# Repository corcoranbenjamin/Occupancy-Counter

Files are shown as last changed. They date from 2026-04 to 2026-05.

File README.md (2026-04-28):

# Occupancy Counter — VL53L5CX + ESP32-C6

Real-time room occupancy tracking using a time-of-flight sensor, with cloud logging to Google Sheets and a live Grafana dashboard.

<p align="center">
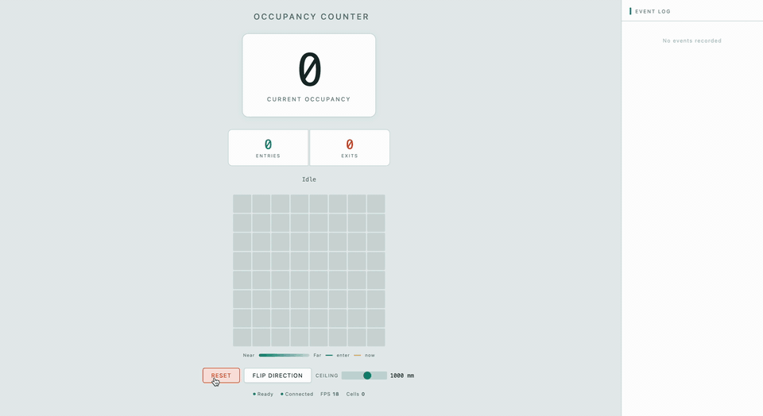
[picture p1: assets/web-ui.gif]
Live web UI showing the 8x8 sensor grid, occupancy count, entries, exits, and event log
  
</p>

A VL53L5CX 8×8 multizone ToF sensor points straight down from above a doorway. At 15 Hz it produces a grid of distance readings. When someone walks through, their head and shoulders appear as a cluster of cells closer than the learned baseline. The firmware detects those clusters, tracks them across the sensor's field of view, and based on the direction of travel classifies each crossing as an **entry** or **exit**.

The ESP32-C6 connects to WiFi (WPA2-Enterprise/eduroam by default, with a WPA2-PSK option for testing), logs snapshots to a Google Sheet, and optionally writes daily CSV files to a micro SD card. Uploads only happen when the doorway is clear so the tracking pipeline is never interrupted by network I/O. A Grafana Cloud dashboard reads the Sheet and displays live occupancy, entries, exits, and occupancy-over-time. The device deep-sleeps outside configurable hours and restores its calibration baseline from flash on wake.

---

## Hardware

| Component | Role |
|---|---|
| **VL53L5CX** (Pololu carrier board) | 8×8 multizone time-of-flight sensor, up to 4 m range |
| **ESP32-C6** | WiFi-capable RISC-V microcontroller running the firmware |
| **Micro SD breakout module** | Optional local CSV logging (SPI) |
| **Momentary push button** on GPIO3 | Hold 2 s to reset counts and clear saved baseline |

### Wiring

**Sensor (I2C):** `VIN→3V3` · `GND→GND` · `SDA→GPIO6` · `SCL→GPIO7` · `LPn→3V3` · `INT→GPIO5`

**SD card (SPI):** `CS→GPIO1` · `SCK→GPIO18` · `MOSI→GPIO19` · `MISO→GPIO20`

**Reset button:** `GPIO3→GND` (uses internal pull-up)

---

## Getting Started

### Prerequisites

- **Arduino IDE** or **arduino-cli** with the **ESP32** board package (≥ 3.x)
- Board selection: **ESP32C6 Dev Module**
- **USB CDC On Boot** must be **Enabled** in board settings for serial output

### Libraries

| Library | Purpose |
|---|---|
| [SparkFun VL53L5CX](https://github.com/sparkfun/SparkFun_VL53L5CX_Arduino_Library) | Sensor driver |
| [ESP-Google-Sheet-Client](https://github.com/mobizt/ESP-Google-Sheet-Client) | Google Sheets API with service-account auth |
| [ESP32WiFiEnterprise](https://github.com/racoonx65/WiFiEnterprise) | WPA2-Enterprise (eduroam) support |

### Setup

1. Clone this repo
2. Copy `secrets_template.h` → `secrets.h`
3. Fill in your eduroam credentials, GCP service account, and Spreadsheet ID
4. (Optional) To use a home WiFi network instead of eduroam, uncomment `USE_HOME_WIFI` and set `HOME_SSID` / `HOME_PASSWORD` in `secrets.h`
5. Flash to ESP32-C6
6. Keep the doorway clear for ~2 seconds while the sensor calibrates

### Google Sheets

Create a Google Sheet with a tab named **Data**. Share it with your GCP service account email (Editor). The firmware appends rows starting at `Data!A2`:

| Column A | Column B | Column C | Column D | Column E |
|---|---|---|---|---|
| EpochTimestamp | Occupancy Count | Entry | Exit | Time (EST) |

### Grafana Dashboard

1. Install the **Google Sheets** data source plugin in Grafana Cloud
2. Configure with your API key and Spreadsheet ID
3. Import `grafana-dashboard.json`
4. The chart panel needs two transformations: convert `EpochTimestamp` to Time (format `X`), convert `Occupancy Count` to Number

| Panel | Type | Color |
|---|---|---|
| Occupancy | Stat (big number) | `#3A82FF` blue |
| Entries | Stat | `#34D399` mint |
| Exits | Stat | `#F87171` coral |
| Occupancy Over Time | Time series | `#22D3EE` cyan |

<p align="center">
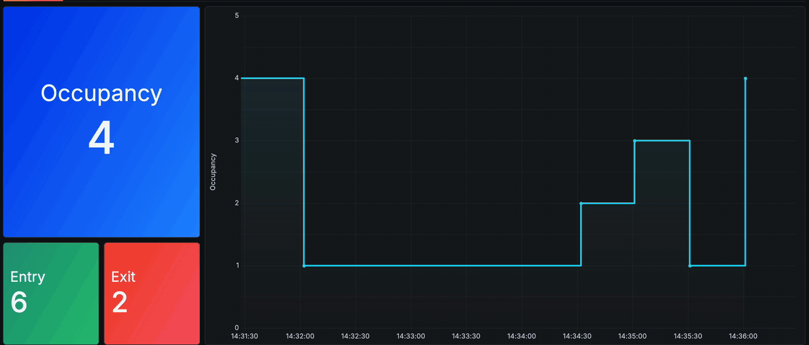
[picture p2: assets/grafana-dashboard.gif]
Grafana dashboard showing live occupancy, entries, exits, and occupancy-over-time chart
  
</p>

---

## How It Works

### Detection & Tracking Pipeline

Each frame at ~15 Hz runs through this pipeline:

1. **Validate** — accept cells with `target_status` 5, 6, or 9 (per VL53L5CX datasheet UM2884) and distance > 0
2. **Min-distance filter** — rolling minimum over the last 3 frames per cell, reducing multipath noise (UM2600 §6.2)
3. **Occupied mask** — a cell is occupied if its filtered distance is above `DETECT_FLOOR_MM` (100 mm), below `DETECT_CEILING_MM` (1000 mm), and after calibration at least `STATIC_MARGIN_MM` (100 mm) shorter than its baseline
4. **BFS blob detection** — flood-fill finds connected clusters of occupied cells; blobs smaller than `MIN_BLOB_SIZE` (2 cells) are discarded
5. **Greedy association** — each blob is matched to its nearest existing track by centroid distance (within 3.0 grid cells)
6. **Track expiry** — unmatched tracks accumulate misses; after a grace period (5 frames) or total timeout (90 frames), the track is evaluated
7. **Spawn** — unmatched blobs become new tracks
8. **Direction evaluation** — `shift = last_row − enter_row`; if the shift exceeds 1.5 rows and the track lived for ≥3 frames, the direction relative to `ENTRY_DIR` determines entry vs exit; occupancy is incremented or decremented accordingly

### Idle-Only Uploads

Google Sheets uploads and SD card writes only occur when `tracking_active` is false (no one in the doorway). This prevents blocking HTTPS calls from stalling the tracking pipeline and causing missed frames or false counts. Data is buffered and sent the moment the doorway clears.

### Calibration & Baseline Persistence

On first boot the sensor averages 30 frames (~2 s) of the empty doorway to learn a per-cell baseline. This baseline is saved to ESP32 NVS flash. On subsequent boots (including wake from deep sleep) the baseline is restored automatically — no recalibration delay.

Holding the reset button for 2 seconds clears the saved baseline, resets all counters, and starts a 10-second countdown so you can clear the doorway before calibration begins.

### Sleep Schedule

When `SLEEP_ENABLED` is set (default), the device:
- Checks the clock every 30 seconds
- At 21:30 (configurable): resets counts, uploads a final row, saves baseline to flash, stops the sensor, unmounts the SD card, turns off WiFi, and enters deep sleep
- At 06:30 (configurable): wakes via timer, reboots, reconnects, restores baseline, and starts tracking with fresh counters
- If it boots outside the active window, it immediately sleeps until the next wake time
- Each sleep is capped at 1 hour for timer reliability; `setup()` re-evaluates on each wake

### SD Card Logging

When `SD_ENABLED` is set (default), a CSV row is written to `/YYYY-MM-DD.csv` on the SD card every 5 minutes (configurable via `SD_LOG_INTERVAL_MS`), independent of the Sheets upload interval. Like Sheets uploads, SD writes only occur when the doorway is clear.

---

## Project Structure

```
OccupancyCounter/
├── OccupancyCounter.ino       Main sketch (setup, loop, WiFi, Sheets, SD, sleep)
├── config.h                    All tuneable constants
├── tracking.h                  OccupancyTracker class (algorithm + NVS persistence)
├── secrets_template.h          Credential placeholders — copy to secrets.h
├── grafana-dashboard.json      Importable Grafana dashboard
├── assets/                     Demo GIFs used in this README
├── tools/
│   └── debug-display/          Standalone debugging sketch (see below)
├── .gitignore                  Excludes secrets.h
└── README.md                   This file
```

---

## Debugging Tools

A standalone debugging sketch lives at [`tools/debug-display/`](tools/debug-display/) for sponsors and future teams who want to validate sensor placement, watch the tracking algorithm in real time, or tune detection thresholds without setting up the full cloud stack.

It runs on the same hardware as the production firmware but replaces Google Sheets and Grafana with a self-hosted WiFi access point and an in-browser visualization of the 8x8 distance grid, occupied cells, blobs, tracks, and entry/exit decisions. No `secrets.h` is required.

See [`tools/debug-display/README.md`](tools/debug-display/README.md) for full instructions, and [`tools/debug-display/CODE_WALKTHROUGH.md`](tools/debug-display/CODE_WALKTHROUGH.md) for a line-by-line explanation of the tracking algorithm aimed at someone reading it for the first time.

---

## Configuration Reference

All compile-time constants are in `config.h`.

### Pins

| Constant | Value | Purpose |
|---|---|---|
| `SDA_PIN` | 6 | I2C data |
| `SCL_PIN` | 7 | I2C clock |
| `INT_PIN` | 5 | Sensor interrupt (active LOW) |
| `RESET_BUTTON_PIN` | 3 | Reset button (active LOW, internal pull-up) |
| `SD_CS_PIN` | 1 | SD chip select |
| `SD_CLK_PIN` | 18 | SD clock |
| `SD_MOSI_PIN` | 19 | SD MOSI |
| `SD_MISO_PIN` | 20 | SD MISO |

### Sensor & Detection

| Constant | Value | Purpose |
|---|---|---|
| `SENSOR_FREQ_HZ` | 15 | Ranging frequency (Hz) |
| `DETECT_FLOOR_MM` | 100 | Ignore closer than this (near-field noise) |
| `DETECT_CEILING_MM` | 1000 | Detection ceiling (mm below sensor) |
| `STATIC_MARGIN_MM` | 100 | Min baseline–reading delta to count as occupied |

### Tracking

| Constant | Value | Purpose |
|---|---|---|
| `MAX_BLOBS` / `MAX_TRACKS` | 4 | Simultaneous blob/track limit |
| `MIN_BLOB_SIZE` | 2 | Min cells for a valid blob |
| `MAX_ASSOC_DIST` | 3.0 | Max centroid distance for track↔blob match |
| `MIN_CROSSING_FRAMES` | 3 | Min frames for a real crossing (~200 ms) |
| `MAX_CROSSING_FRAMES` | 90 | Timeout for lingering track (~6 s) |
| `MIN_CENTROID_SHIFT` | 1.5 | Min row shift to count as a crossing |
| `MISS_GRACE_FRAMES` | 5 | Frames to tolerate dropout (~333 ms) |
| `ENTRY_DIR` | -1 | Row direction that counts as entry |
| `MIN_FILTER_DEPTH` | 3 | Rolling min-filter window (frames) |

### Calibration

| Constant | Value | Purpose |
|---|---|---|
| `CALIB_FRAMES` | 30 | Frames to average for baseline (~2 s) |
| `CALIB_MAX_DIST_MM` | 4000 | Default baseline for cells with no valid readings |

### Sleep Schedule

| Constant | Value | Purpose |
|---|---|---|
| `SLEEP_ENABLED` | 1 | Set to 0 to run 24/7 |
| `SLEEP_HOUR` / `SLEEP_MINUTE` | 21 / 30 | Sleep at 9:30 PM |
| `WAKE_HOUR` / `WAKE_MINUTE` | 6 / 30 | Wake at 6:30 AM |
| `SLEEP_CHECK_INTERVAL_MS` | 30000 | Clock check interval |

### Networking & Logging

| Constant | Value | Purpose |
|---|---|---|
| `SHEETS_UPLOAD_INTERVAL_MS` | 30000 | Sheets upload every 30 s (when idle) |
| `SD_LOG_INTERVAL_MS` | 300000 | SD backup every 5 min (when idle) |
| `WIFI_CHECK_INTERVAL_MS` | 5000 | WiFi health check interval |
| `MAX_RECONNECT_ATTEMPTS` | 5 | Reconnect cap per boot |
| `NTP_SERVER` | `pool.ntp.org` | Time server |
| `TZ_INFO` | `EST5EDT,...` | POSIX timezone (Eastern + DST) |
| `SD_ENABLED` | 1 | Set to 0 to disable SD logging |

---

## Serial Monitor Reference

| Tag | Meaning | Example |
|---|---|---|
| `[INIT]` | Sensor init | `[INIT] 8x8 @ 15 Hz, INT on GPIO5` |
| `[WIFI]` | WiFi status | `[WIFI] Connected — IP 10.0.0.50  RSSI -45 dBm` |
| `[TIME]` | NTP sync | `[TIME] NTP configured` |
| `[AUTH]` | Sheets token | `[AUTH] OAuth2.0 access token — ready` |
| `[CAL]` | Calibration | `[CAL] Baseline restored from flash — skipping calibration` |
| `[RUN]` | Tracking active | `[RUN] Active — ceiling 1000 mm, shift 1.5 rows, max 4 tracks` |
| `[SHEET]` | Upload result | `[SHEET] OK — occ:1  in:3  out:2  heap:177536` |
| `[SD]` | SD card | `[SD] Card mounted — 7640MB` |
| `[SLEEP]` | Sleep events | `[SLEEP] 21:30 — time to sleep` |
| `[BTN]` | Button reset | `[BTN] Reset — clear the doorway!` |

---

## Daily Lifecycle

1. **06:30** — ESP32 wakes from deep sleep, reboots
2. WiFi connects, NTP syncs, Google Sheets authenticates, SD card mounts
3. Baseline restored from flash — tracking starts immediately
4. Counts begin at zero for the new day
5. Occupancy logged to Sheet every 30 s and SD every 5 min (only when doorway is clear); Grafana auto-refreshes
6. **21:30** — counts reset, final upload, baseline saved, sensor stopped, SD unmounted, WiFi off, deep sleep
7. Repeat

---

## References

- [VL53L5CX Datasheet (UM2884)](https://www.st.com/resource/en/user_manual/um2884-a-guide-to-using-the-vl53l5cx-multizone-timeofflight-ranging-sensor-with-wide-field-of-view-ultra-lite-driver-uld-s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) — target_status codes, resolution modes
- [VL53L5CX datasheet (DS13754)](https://www.st.com/resource/en/datasheet/vl53l5cx.pdf) — module specs, FoV, range performance, power; ranging mode overview (full ULD API and output fields in UM2884 above)
- [People-Counting App Note (UM2600)](https://www.st.com/resource/en/user_manual/um2600-counting-people-with-the-vl53l1x-longdistance-ranging-timeofflight-sensor-stmicroelectronics.pdf) — min-distance filter (§6.2); originally for VL53L1X, technique adapted here
- [SparkFun VL53L5CX Library](https://github.com/sparkfun/SparkFun_VL53L5CX_Arduino_Library)
- [ESP-Google-Sheet-Client](https://github.com/mobizt/ESP-Google-Sheet-Client)
- [ESP32WiFiEnterprise](https://github.com/racoonx65/WiFiEnterprise)

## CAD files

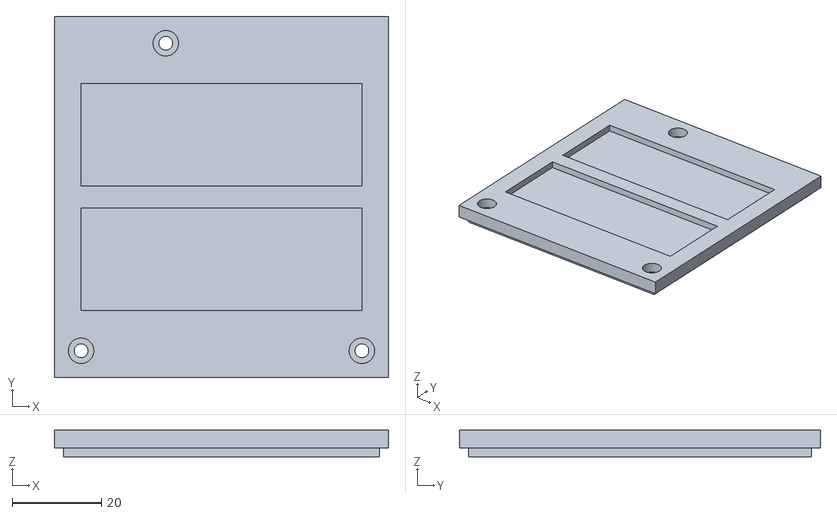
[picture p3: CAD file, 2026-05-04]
Enclosure CAD Files/Final_Enclosure_Lid.stl
75.0 x 81.0 x 6.00

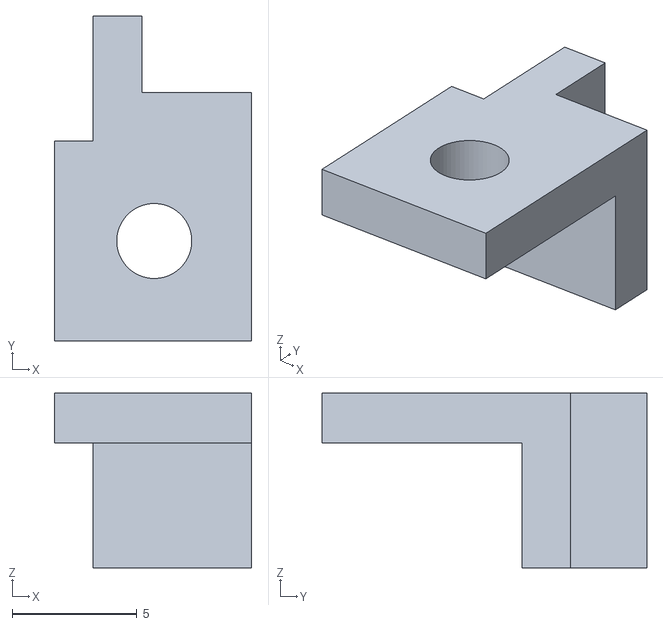
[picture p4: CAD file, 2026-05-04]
Enclosure CAD Files/Button_Holder.stl
7.90 x 13.0 x 7.00

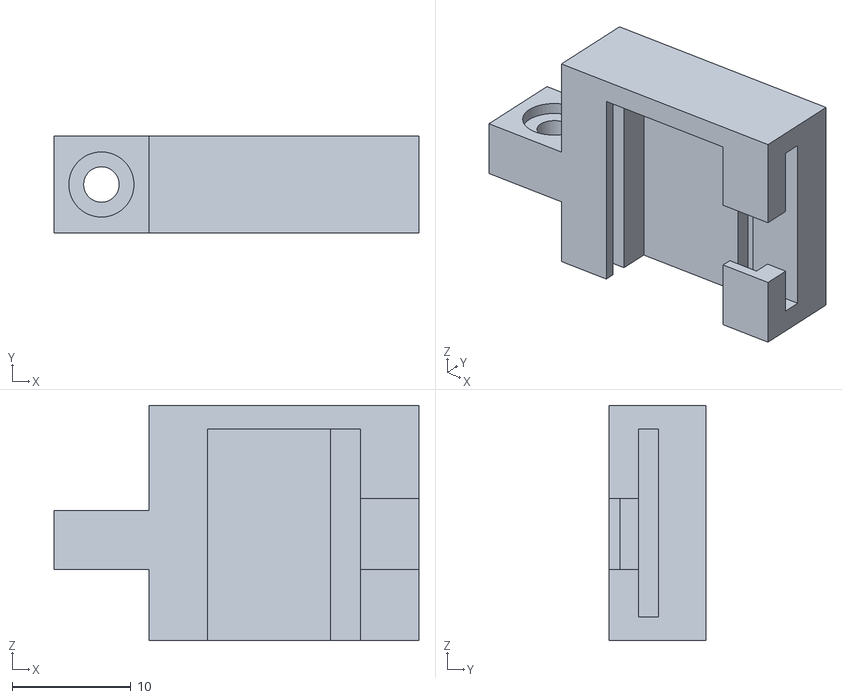
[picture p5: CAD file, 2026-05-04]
Enclosure CAD Files/ToF_Holder.stl
30.8 x 8.20 x 19.9

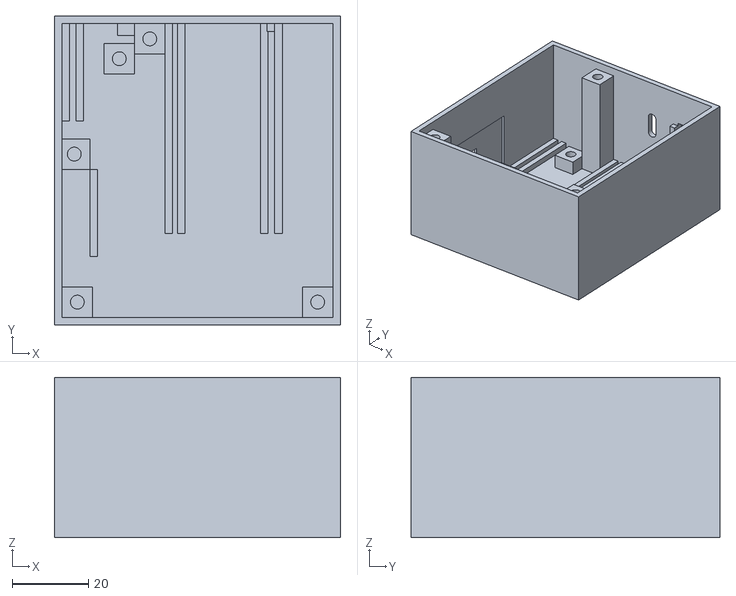
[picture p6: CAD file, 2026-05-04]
Enclosure CAD Files/Final_Enclosure.stl
75.0 x 81.0 x 42.0

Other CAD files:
Enclosure CAD Files/Button_Holder.f3d
Enclosure CAD Files/Final_Enclosure.f3d
Enclosure CAD Files/Final_Enclosure_Lid.f3d
Enclosure CAD Files/ToF_Holder.f3d

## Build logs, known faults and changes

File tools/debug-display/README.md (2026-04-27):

# Tracking Debug Display

A standalone Arduino sketch for visually debugging the VL53L5CX tracking algorithm. It runs on the same hardware as the production firmware but replaces the cloud logging stack with a self-hosted WiFi access point and an in-browser debug page.

Use it for sensor placement, calibration validation, and tuning the tracker without needing eduroam, Google Sheets, or Grafana.

---

## What it shows

When you join the device's access point and load `http://192.168.4.1` you get a live page with:

- The full 8x8 distance grid, color-coded by depth.
- The learned baseline distance for each cell.
- The occupied mask after baseline subtraction.
- Detected blobs (BFS connected components) with their centroids.
- Persistent tracks across frames, including their `enter_row -> last_row` shift.
- Live entry / exit counts and the most recent crossing decision.

This makes it easy to answer questions like:

- Is the sensor mounted high enough?
- Is the baseline being learned with the doorway actually clear?
- Is a person being detected as one blob or fragmenting into several?
- Is the row-shift threshold appropriate for this doorway width?

The web UI is the same one shown in the GIF at the top of the parent repository's README.

---

## Hardware

Identical to the production firmware (parent repo `OccupancyCounter.ino`):

| Pin | Connection |
|---|---|
| `GPIO6` | I2C SDA |
| `GPIO7` | I2C SCL |
| `GPIO5` | Sensor INT |
| `GPIO3` | Reset button to GND |
| `3V3` / `GND` | Sensor power, sensor `LPn` tied to `3V3` |

Board: **ESP32C6 Dev Module** (`esp32` core 3.x).

The SD card and Google Sheets pipeline are not used here — the debug build only needs the sensor and the ESP32.

---

## Library

- [SparkFun VL53L5CX Arduino Library](https://github.com/sparkfun/SparkFun_VL53L5CX_Arduino_Library)

That is the only required library. No `secrets.h`, no service account, no eduroam credentials.

---

## Usage

1. Open `TrackingDebugDisplay.ino` in the Arduino IDE.
2. Select board: **ESP32C6 Dev Module**, with **USB CDC On Boot** enabled.
3. Hold `BOOT` while plugging in the USB cable, then upload.
4. Once flashed, the device broadcasts an open SSID:
   - **SSID:** `OccupancyCounter`
   - **Password:** `12345678`
5. Connect a laptop or phone to that SSID.
6. Browse to **http://192.168.4.1**.
7. Hold the reset button for 2 s to wipe the saved baseline and recalibrate (clear the doorway during the 10 s countdown).

---

## How it relates to the production firmware

| | Production (`OccupancyCounter.ino`) | Debug display (this folder) |
|---|---|---|
| WiFi | WPA2-Enterprise (eduroam) or WPA2-PSK | Open access point hosted by the device |
| Logging | Google Sheets + SD card CSV | None — live web UI only |
| Dashboard | Grafana Cloud | Built-in HTML page |
| Sleep schedule | 21:30 - 06:30 deep sleep | Always on while powered |
| Tracking algorithm | Identical | Identical |

Both sketches share the same `tracking.h` algorithm philosophy (multi-blob BFS, greedy track association, row-shift direction evaluation) but each carries its own copy. **Do not try to share `tracking.h` between the two folders** — they are tuned independently and may diverge over time.

---

## Further reading

- [`CODE_WALKTHROUGH.md`](CODE_WALKTHROUGH.md) — line-by-line explanation of the tracking algorithm written for someone learning it for the first time.
- Parent repo [README](../../README.md) — full project context, production firmware, dashboard setup.

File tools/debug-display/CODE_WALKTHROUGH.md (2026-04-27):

# Occupancy Counter VL53L5CX — Code Walkthrough

## What This Project Does

A VL53L5CX time-of-flight sensor is mounted on the ceiling above a doorway, pointing straight down. It outputs an 8×8 grid of distance measurements 15 times per second. When a person walks underneath, some cells read closer than the empty doorway. The software detects those clusters, tracks them as they move across rows, and when they disappear off the other side, decides: was that an entry or an exit?

An ESP32-C3 microcontroller runs the sensor, the tracking algorithm, and a WiFi access point with a web dashboard showing the live count.

### Hardware

| Component | Role |
|---|---|
| **VL53L5CX** (on Pololu carrier board) | 8×8 multizone time-of-flight sensor, up to 4 m range |
| **ESP32-C3-DevKitC-02** | WiFi-capable RISC-V microcontroller running the firmware |
| **Physical button** on GPIO9 | Hold 2 seconds to reset counts |

Wiring: `VIN→3V3`, `GND→GND`, `SDA→GPIO4`, `SCL→GPIO5`, `LPn→3V3`, `INT→GPIO6`.

### References

- **VL53L5CX datasheet (UM2884):** [st.com/resource/en/user_manual/um2884](https://www.st.com/resource/en/user_manual/um2884-a-guide-to-using-the-vl53l5cx-multizone-timeofflight-ranging-sensor-with-a-wide-field-of-view-stmicroelectronics.pd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) — target_status codes, resolution modes, ranging frequency
- **VL53L5CX ranging guide (UM2600):** [st.com/resource/en/user_manual/um2600](https://www.st.com/resource/en/user_manual/um2600-vl53l1x-ranging-and-calibration-guide-stmicroelectronics.pdf) — min-distance filter technique (§6.2)
- **SparkFun VL53L5CX Arduino Library:** [github.com/sparkfun/SparkFun_VL53L5CX_Arduino_Library](https://github.com/sparkfun/SparkFun_VL53L5CX_Arduino_Library) — the driver used to communicate with the sensor
- **ESP32-C3 Technical Reference:** [docs.espressif.com](https://docs.espressif.com/projects/esp-idf/en/latest/esp32c3/) — GPIO interrupts, I2C, WiFi AP mode
- **Arduino ESP32 Core:** [github.com/espressif/arduino-esp32](https://github.com/espressif/arduino-esp32) — `WebServer`, `WiFi`, `Wire` libraries

---

## Project Structure

```
OccupancyCounterVL53L5CX/
├── OccupancyCounterVL53L5CX.ino   Main Arduino sketch (setup, loop, web server)
├── config.h                        All tuneable constants (pins, thresholds, timing)
├── tracking.h                      OccupancyTracker class (the detection/tracking algorithm)
└── web_page.h                      HTML/CSS/JS dashboard served by the ESP32
```

---

## File-by-File Breakdown

---

### config.h — Tuneable Constants

This file contains only `#define` values. It is the single place to adjust behavior without touching logic. Every constant is used by name in the other files.

#### Pin Definitions

| Constant | Value | Purpose |
|---|---|---|
| `SDA_PIN` | 4 | I2C data line to the VL53L5CX |
| `SCL_PIN` | 5 | I2C clock line to the VL53L5CX |
| `INT_PIN` | 6 | Interrupt line — sensor pulls LOW when a new frame is ready |
| `RESET_BUTTON_PIN` | 9 | Physical button; hold 2 s to reset occupancy counts |

#### WiFi

| Constant | Value | Purpose |
|---|---|---|
| `AP_MODE` | (defined) | Enables Access Point mode — the ESP32 creates its own WiFi network |
| `AP_SSID` | `"OccupancyCounter"` | Network name |
| `AP_PASSWORD` | `"12345678"` | Network password |
| `STA_MODE` | (commented out) | Alternative: connect to an existing network as a client |

Only one mode should be active at a time. If `STA_MODE` is enabled and the connection fails, the code falls back to AP mode automatically.

#### Sensor

| Constant | Value | Purpose |
|---|---|---|
| `SENSOR_I2C_ADDR` | `0x29` | Default I2C address of the VL53L5CX (per UM2884 §3.2) |
| `SENSOR_FREQ_HZ` | 15 | Frames per second. The sensor supports 1–60 Hz; 15 balances responsiveness and power |
| `I2C_CLOCK_HZ` | 400000 | 400 kHz I2C Fast Mode |

#### Detection

| Constant | Value | Purpose |
|---|---|---|
| `DETECT_CEILING_MM` | 1000 | Anything closer than 1000 mm (1 m) below the sensor is "something is there." Adjustable at runtime via the web UI slider (200–2000 mm range). |

#### Tracking Parameters

| Constant | Value | Purpose |
|---|---|---|
| `MAX_BLOBS` | 4 | Maximum simultaneous blob detections per frame |
| `MAX_TRACKS` | 4 | Maximum simultaneous persistent tracks |
| `MIN_BLOB_SIZE` | 2 | Minimum connected occupied cells to count as a real blob (rejects single-cell noise) |
| `MAX_ASSOC_DIST` | 3.0 | Maximum centroid distance (in grid cells) for matching a blob to an existing track between frames |
| `MIN_CROSSING_FRAMES` | 3 | A track must last at least 3 frames (~200 ms) to count as a real crossing (rejects brief noise) |
| `MAX_CROSSING_FRAMES` | 90 | A track lasting more than 90 frames (~6 s) is force-expired (person standing still, not crossing) |
| `MIN_CENTROID_SHIFT` | 1.5 | The centroid must move at least 1.5 grid rows from entry to exit to count (rejects partial entries) |
| `MISS_GRACE_FRAMES` | 5 | If a track loses its blob match for 5 consecutive frames (~333 ms), expire it (handles brief sensor dropouts) |
| `ENTRY_DIR` | -1 | Which row direction is "entering." `1` = moving toward higher rows = entry. `-1` = moving toward lower rows = entry. Flippable at runtime via the web UI. |

#### Noise Filtering

| Constant | Value | Purpose |
|---|---|---|
| `MIN_FILTER_DEPTH` | 3 | Keep the last 3 frames per cell, take the minimum distance. This is the "min-distance filter" recommended in ST's ranging guide (UM2600 §6.2). Smooths out transient noise spikes. |
| `STATIC_MARGIN_MM` | 100 | After calibration, a cell must be at least 100 mm closer than baseline to be "occupied." This rejects the door frame, walls, and floor from being detected as people. |

#### Calibration

| Constant | Value | Purpose |
|---|---|---|
| `CALIB_FRAMES` | 30 | Average 30 frames (~2 seconds at 15 Hz) of the empty doorway to learn the baseline distances |
| `CALIB_MAX_DIST_MM` | 4000 | If a cell never got a valid reading during calibration, assume 4000 mm (sensor max range) |

---

### tracking.h — The OccupancyTracker Class

This is the brain of the system. It contains all detection, tracking, and counting logic.

#### The 8×8 Grid

The VL53L5CX returns 64 distance readings arranged in an 8×8 grid, stored in row-major order (index 0 = top-left, index 63 = bottom-right):

```
     col  0    1    2    3    4    5    6    7
row 0   [ 0] [ 1] [ 2] [ 3] [ 4] [ 5] [ 6] [ 7]    ← entry side (when ENTRY_DIR = 1)
    1   [ 8] [ 9] [10] [11] [12] [13] [14] [15]
    2   [16] [17] [18] [19] [20] [21] [22] [23]
    3   [24] [25] [26] [27] [28] [29] [30] [31]
    4   [32] [33] [34] [35] [36] [37] [38] [39]
    5   [40] [41] [42] [43] [44] [45] [46] [47]
    6   [48] [49] [50] [51] [52] [53] [54] [55]
    7   [56] [57] [58] [59] [60] [61] [62] [63]    ← exit side
```

To convert a flat index to row/column: `row = index / 8`, `col = index % 8`.
Neighbor offsets: up = `index - 8`, down = `index + 8`, left = `index - 1`, right = `index + 1`.

#### Data Structures

**Public fields** (read by the web server to build JSON responses):

| Field | Type | Purpose |
|---|---|---|
| `current_distances[64]` | `int16_t[]` | Raw distance readings from the latest frame (mm) |
| `occupied[64]` | `bool[]` | Binary mask: is something detected in this cell? |
| `tracking_active` | `bool` | Is at least one track currently alive? |
| `enter_centroid` | `float` | The longest-lived track's starting row position |
| `current_centroid` | `float` | The longest-lived track's current row position |
| `occ_count` | `int` | How many cells are occupied this frame |
| `num_tracks` | `int` | How many active tracks exist right now |
| `occupancy` | `int` | **THE COUNT** — entries minus exits (never goes below 0) |
| `total_entries` | `int` | Cumulative entry count since last reset |
| `total_exits` | `int` | Cumulative exit count since last reset |
| `detect_ceiling` | `int` | Current ceiling threshold in mm (adjustable at runtime) |
| `entry_dir` | `int8_t` | +1 or -1, which row direction counts as "entry" (flippable at runtime) |
| `frames_processed` | `uint32_t` | Total frames processed since boot |
| `baseline[64]` | `int16_t[]` | Learned empty-doorway distances from calibration |
| `calibrated` | `bool` | Has calibration completed? |

**Private fields:**

| Field | Type | Purpose |
|---|---|---|
| `_zone_valid[64]` | `bool[]` | Per-cell: did the sensor return a trustworthy reading this frame? |
| `_min_buf[64][3]` | `int16_t[][]` | Circular buffer holding last 3 distance readings per cell (for min filter) |
| `_filter_idx` | `uint8_t` | Current write position in the circular buffer (cycles 0→1→2→0→...) |
| `_blobs[4]` | `Blob[]` | This frame's detected blobs (each has a row/col centroid) |
| `_num_blobs` | `int` | How many blobs were found this frame |
| `_visited[64]` | `bool[]` | Scratch array for BFS flood-fill |
| `_queue[64]` | `uint8_t[]` | Scratch queue for BFS flood-fill |
| `_tracks[4]` | `Track[]` | Persistent tracked objects that live across frames |
| `_calib_count` | `int` | How many calibration frames collected so far |
| `_calib_accum[64]` | `int32_t[]` | Sum of valid distances per cell during calibration |
| `_calib_n[64]` | `int[]` | Count of valid readings per cell during calibration |

**The Track struct:**

| Field | Type | Purpose |
|---|---|---|
| `active` | `bool` | Is this track slot currently in use? |
| `enter_row` | `float` | Row centroid when the track was first created (where the person "entered" the field of view) |
| `last_row` | `float` | Row centroid the last time the track was matched to a blob |
| `row`, `col` | `float` | Current 2-D centroid position (used for distance matching) |
| `start_frame` | `uint32_t` | Frame number when this track was born |
| `frames` | `int` | Total frames this track has been matched to a blob |
| `misses` | `int` | Consecutive frames where no blob matched this track |

#### Functions

##### `init()`

Zeros out all arrays and state. Sets `detect_ceiling` and `entry_dir` to their config defaults. Fills the min-filter buffer with `DIST_INVALID` (4001) so no ghost readings appear before real data arrives. Marks all track slots as inactive. Called once in `setup()`.

##### `addCalibrationFrame(dist, status)` — Learning the empty doorway

Called once per frame during the first ~2 seconds (while `calibrated` is false). For each of the 64 cells, if the sensor reading is valid, it accumulates the distance into `_calib_accum[i]` and increments `_calib_n[i]`. After 30 frames, it computes the average distance per cell → this becomes `baseline[i]`, the "this is how far away the floor/walls are when nobody is there" reference. If a cell never got a valid reading, it defaults to 4000 mm. Returns `true` when calibration finishes.

##### `resetCalibration()`

Clears the accumulators so calibration can restart from scratch.

##### `processFrame(dist, status)` — The main pipeline

This is the heart of the system. Called every frame (~15 Hz). It runs 5 stages:

**Stage 1: Validate and store raw data** (tracking.h lines 121–124)

For each of the 64 cells, checks if the sensor's `target_status` byte is one of the valid codes (5, 6, or 9 — see `_isValid()` below). Stores the result in `_zone_valid[i]`. Also copies the raw distance into `current_distances[i]`.

**Stage 2: `_updateMinFilter()`** (tracking.h lines 195–199)

Writes this frame's distances into the circular buffer `_min_buf`. Invalid cells get `DIST_INVALID` (4001) written instead, so they can't accidentally register as "close." Advances the circular index. This implements ST's recommended "min-distance filter" (UM2600 §6.2) — by keeping 3 frames and taking the minimum, brief noise spikes where the distance jumps high for one frame get rejected.

**Stage 3: `_detectOccupied()`** (tracking.h lines 212–222)

For each cell, calls `_filteredDist(i)` which returns the minimum distance across the last 3 frames. Then decides if that cell is "occupied":

- **Before calibration:** if the filtered distance is > 0, below the ceiling threshold, and not `DIST_INVALID`, the cell is occupied. This is a simple range check.
- **After calibration:** additionally requires that `baseline[i] - filtered > STATIC_MARGIN_MM` (100 mm). This is the static-object rejection. Example: the door frame consistently reads 800 mm. The baseline learned 800 mm. So `800 - 800 = 0`, which is not > 100, and the door frame is correctly ignored. But a person standing at 600 mm: `800 - 600 = 200 > 100`, so they are detected.

**Stage 4: `_findBlobs()`** (tracking.h lines 225–262)

BFS (Breadth-First Search) flood-fill on the `occupied[]` grid. Scans cells 0 through 63 in order. When it finds an occupied cell that hasn't been visited, it starts a BFS from that cell, visiting all 4-connected neighbors (up, down, left, right) that are also occupied. This groups connected occupied cells into a "blob."

As it visits each cell, it accumulates the row and column coordinates to compute the blob's centroid: `centroid_row = sum_of_rows / count`, `centroid_col = sum_of_cols / count`.

If the blob has at least `MIN_BLOB_SIZE` (2) cells, it's saved. Up to 4 blobs per frame.

**What is a centroid?**

The centroid is the average position of all occupied cells in a blob — its geometric center. It's a fractional (row, col) coordinate that doesn't necessarily land on any actual cell.

For each cell BFS visits, the flat index (0–63) is converted to row/col via `row = cell / 8`, `col = cell % 8`. The row and column values are summed, then divided by the cell count:

```
centroid_row = sum_of_rows / count
centroid_col = sum_of_cols / count
```

Example: a person's head/shoulders occupy 4 cells:

```
     col 0  1  2  3  4  5  6  7
row 3   [ ][ ][XX][XX][ ][ ][ ][ ]
row 4   [ ][ ][XX][XX][ ][ ][ ][ ]
```

Occupied cells are at (3,2), (3,3), (4,2), (4,3):
- `row_sum = 3 + 3 + 4 + 4 = 14`, `col_sum = 2 + 3 + 2 + 3 = 10`, `count = 4`
- **Centroid = (14/4, 10/4) = (3.5, 2.5)**

As the person walks from row 1 to row 6, the centroid's row component smoothly increases from ~1.5 to ~5.5. The tracker records the row at entry (`enter_row`) and the row when the track expires (`last_row`). The difference — the **row shift** — is what decides entry vs exit:

```
shift = last_row - enter_row
      = 5.5 - 1.5
      = +4.0 rows (moved toward higher rows)
```

The column component is only used for **matching** — computing the Euclidean distance between a blob and an existing track so the tracker can figure out which blob belongs to which person across frames.

**Stage 5: `_updateTracks()`** (tracking.h lines 265–339)

The most complex function. It has 4 sub-steps:

**5a. Associate** (lines 269–293): Greedy nearest-centroid matching. For each iteration, finds the globally closest (existing track, new blob) pair by Euclidean distance between their centroids. If the distance is within `MAX_ASSOC_DIST` (3.0 grid cells), pairs them: updates the track's position to the blob's centroid, increments its frame count, resets its miss counter. Marks both as "taken." Repeats until no more valid pairs exist.

**5b. Expire** (lines 295–304): Any active track that didn't get matched to a blob this frame gets a miss. If its misses exceed `MISS_GRACE_FRAMES` (5 frames), or it has been alive longer than `MAX_CROSSING_FRAMES` (90 frames), it is expired: call `_evaluateTrack()` to decide if it was an entry or exit, then deactivate it.

**5c. Spawn** (lines 306–321): Any blob that wasn't matched to an existing track becomes a new track. Its `enter_row` is recorded — this is where the person "entered" the sensor's field of view.

**5d. Expose** (lines 323–338): Counts active tracks and finds the "primary" one (the one that has been alive the longest). Exports its `enter_row` and current `row` as `enter_centroid` and `current_centroid` for the web UI to display.

##### `_evaluateTrack(t)` — The entry/exit decision (tracking.h lines 345–358)

This is the core counting logic. When a track expires (the person has left the field of view):

1. **Duration check:** If the track existed for fewer than `MIN_CROSSING_FRAMES` (3 frames, ~200 ms), discard it — too brief to be a real person.
2. **Shift check:** Compute `shift = last_row - enter_row`. If `|shift| < MIN_CENTROID_SHIFT` (1.5 rows), discard — the person didn't move far enough across the grid (maybe poked their head in and pulled back).
3. **Direction check:** If `shift > 0`, the person moved toward higher row numbers. If that matches `entry_dir`, it's an **entry** (occupancy++ and total_entries++). Otherwise it's an **exit** (total_exits++, and occupancy-- but clamped to never go below 0).

##### `resetCount()`

Zeros `occupancy`, `total_entries`, `total_exits`. Deactivates all tracks. Called by the web UI "Reset" button or the physical reset button.

##### `resetTracking()`

Deactivates all tracks but preserves the counters. Called when the ceiling threshold is changed at runtime (since the occupied mask changes, existing tracks become invalid).

##### `_isValid(status)` — Sensor reading validation (tracking.h line 193)

Returns `true` if the VL53L5CX `target_status` byte is 5, 6, or 9. These are defined in ST's UM2884 datasheet:
- **5** = range valid
- **6** = range valid but large sigma (noisy measurement, still usable)
- **9** = range valid, detected by cross-talk compensation

All other status codes (0–4, 7, 8, 10+) indicate invalid or failed measurements.

##### `_filteredDist(zone)` — Min-filter readout (tracking.h lines 201–206)

Returns the minimum distance across the last `MIN_FILTER_DEPTH` (3) frames for a given cell. This is how the min-distance filter produces its output — by taking the minimum, any single-frame spike where the distance jumps to a large value is overridden by the valid readings from the adjacent frames.

---

### OccupancyCounterVL53L5CX.ino — Main Arduino Sketch

This file wires everything together: initializes hardware, runs the main loop, serves the web interface.

#### Global State

| Variable | Type | Purpose |
|---|---|---|
| `sensor` | `SparkFun_VL53L5CX` | Sensor driver object (from SparkFun library) |
| `sensorData` | `VL53L5CX_ResultsData` | Buffer where the library writes raw results |
| `tracker` | `OccupancyTracker` | The tracking engine (from tracking.h) |
| `server` | `WebServer` | HTTP server on port 80 (from ESP32 Arduino core) |
| `sensorDataReady` | `volatile bool` | Flag set by the interrupt service routine when the sensor has a frame ready |
| `resetBtnDown` | `unsigned long` | Timestamp (ms) when the physical button was first pressed |
| `resetBtnActive` | `bool` | Debounce flag for the physical button |

#### `onSensorInt()` — Interrupt Service Routine (.ino line 37)

```cpp
void IRAM_ATTR onSensorInt() { sensorDataReady = true; }
```

Runs in hardware interrupt context when GPIO6 (INT_PIN) goes LOW — meaning the sensor has a new frame ready. Simply sets a flag. `IRAM_ATTR` keeps the function in RAM for fast execution (required for ISRs on ESP32). The `volatile` keyword on the flag variable ensures the compiler doesn't optimize away the read in `loop()`.

This is **interrupt-driven** sensing — the CPU sleeps between frames instead of continuously polling the sensor over I2C.

#### `setup()` — Runs once at boot (.ino lines 48–67)

1. Start serial at 115200 baud (for debug output via USB)
2. Configure GPIO9 as input with internal pull-up (for the physical reset button)
3. Start I2C bus on GPIO4 (SDA) and GPIO5 (SCL) at 400 kHz
4. `initSensor()` — find and configure the VL53L5CX
5. `connectWiFi()` — start the WiFi access point
6. `setupRoutes()` — register HTTP endpoints
7. Start the web server
8. `tracker.init()` — zero out all tracker state
9. Print startup summary to Serial

#### `loop()` — Runs continuously (.ino lines 69–94)

1. `server.handleClient()` — check if any HTTP request came in; if so, serve it
2. `handleResetButton()` — check if the physical button is being held
3. Check `sensorDataReady` — if the interrupt hasn't fired, call `delay(5)` and return. The 5 ms delay lets the RTOS idle task run, which enables the ESP32's automatic light sleep (CPU sleeps until the next interrupt or WiFi beacon).
4. If a frame is ready: clear the flag, read the data via I2C with `sensor.getRangingData()`, copy `distance_mm[]` and `target_status[]` into local arrays, pass them to `tracker.processFrame()`
5. If the tracker isn't calibrated yet, feed the frame to `addCalibrationFrame()`. When it returns `true` (30 frames collected), print the baseline grid to Serial.

#### `initSensor()` (.ino lines 98–118)

Tries to contact the VL53L5CX over I2C up to 5 times with 2-second delays between attempts. If it never responds, halts forever with an error message (the device is useless without the sensor). On success:
- Sets resolution to 8×8 (64 zones)
- Sets ranging frequency to 15 Hz
- Starts continuous ranging
- Configures GPIO6 as an interrupt input — the sensor pulls it LOW on every new frame

#### `connectWiFi()` (.ino lines 120–139)

Two compile-time paths controlled by `#ifdef`:

- **AP mode** (enabled by default): Creates a WiFi network named "OccupancyCounter" with password "12345678". The ESP32's IP is 192.168.4.1. Connect your phone or laptop to this network and open that IP in a browser.
- **STA mode** (commented out in config.h): Connects to an existing WiFi network as a client. If connection fails after 20 seconds (40 × 500 ms), automatically falls back to AP mode.

#### `setupRoutes()` — HTTP Endpoints (.ino lines 143–167)

| Route | Method | What it does |
|---|---|---|
| `/` | GET | Serves the full HTML/CSS/JS dashboard from `web_page.h` |
| `/data` | GET | Returns JSON with all tracker state (polled by the dashboard every 200 ms) |
| `/reset` | GET | Zeros occupancy, entries, exits; kills all tracks |
| `/flip` | GET | Reverses `entry_dir` (multiplies by -1) — swaps which direction is "in" vs "out" |
| `/config?ceiling=N` | GET | Changes the detection ceiling threshold at runtime (clamped to 200–2000 mm); resets active tracks |

#### `sendJson()` — Build JSON response (.ino lines 171–208)

Builds a JSON string by concatenating tracker fields. Uses the `F()` macro to keep string literals in flash memory (saves RAM on the ESP32). The JSON payload includes:

- `occupancy`, `entries`, `exits` — the counts
- `ceiling`, `frames` — configuration and status
- `occ_n` — how many cells are occupied right now
- `tracking`, `num_tracks`, `enter_row`, `cur_row` — live tracking state for the UI
- `cal` — whether calibration is complete
- `distances[64]` — distance for occupied cells, -1 for unoccupied (used by the heatmap grid)
- `occupied[64]` — 1/0 binary mask (used for the green highlight outlines on the grid)

#### `handleResetButton()` (.ino lines 212–221)

Simple hold-to-reset debouncing:
1. Read GPIO9. If LOW (button pressed) and wasn't previously active, record the timestamp.
2. If released, clear the active flag.
3. If held continuously for ≥ 2000 ms (`RESET_HOLD_MS`), call `tracker.resetCount()`.

#### `printBaseline()` (.ino lines 223–230)

Debug helper. After calibration completes, prints the 8×8 baseline distance grid to Serial in a formatted table so you can verify the sensor is reading reasonable values for the empty doorway.

---

### web_page.h — The Dashboard

Contains a single `const char[]` in PROGMEM (flash memory) with the complete HTML, CSS, and JavaScript for the web dashboard. The ESP32 serves this at `/`.

The dashboard polls `/data` every 200 ms via `fetch()`, parses the JSON, and updates:
- The big occupancy number
- Entry/exit counters
- An 8×8 heatmap grid showing live distance readings (colored by proximity)
- Green outlines on occupied cells
- Centroid tracking lines (enter position and current position)
- A tracking status line showing direction and row shift
- An event log sidebar recording each entry/exit with timestamps
- A ceiling slider for runtime adjustment
- Reset and Flip Direction buttons

---

## How It All Fits Together — One Complete Cycle

```
1.  Sensor finishes measuring
         │
         ▼
2.  Pulls INT_PIN (GPIO6) LOW
         │
         ▼
3.  onSensorInt() ISR fires → sets sensorDataReady = true
         │
         ▼
4.  loop() sees the flag → reads 64 distances + 64 statuses via I2C
         │
         ▼
5.  processFrame() runs the 5-stage pipeline:
         │
         ├─ Stage 1: Validate readings (_isValid checks status codes 5, 6, 9)
         ├─ Stage 2: Min-filter (smooth noise across 3 frames)
         ├─ Stage 3: Detect occupied cells (ceiling check + baseline comparison)
         ├─ Stage 4: BFS flood-fill → find connected blobs → compute centroids
         └─ Stage 5: Match blobs to tracks → expire old tracks → spawn new tracks
                │
                ▼
6.  If a track expired → _evaluateTrack() checks row shift → increments
    occupancy (entry) or decrements it (exit)
         │
         ▼
7.  Meanwhile, the browser calls /data every 200 ms
         │
         ▼
8.  sendJson() reads the tracker's public fields → returns JSON
         │
         ▼
9.  JavaScript updates the dashboard display
```

The sensor measures. The tracker thinks. The web server reports.

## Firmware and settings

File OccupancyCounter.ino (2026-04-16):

// ============================================================================
// Occupancy Counter — VL53L5CX + ESP32-C6 + eduroam + Google Sheets
// ============================================================================
//
// Multi-blob tracking on an 8×8 ToF grid.  Occupancy snapshots are appended
// to a Google Sheet via the Sheets API (service-account auth over
// WPA2-Enterprise / eduroam).  Uploads only occur when the doorway is clear
// to avoid stalling the tracking pipeline.
//
// Hardware:  Pololu VL53L5CX carrier → ESP32-C6
//   VIN→3V3  GND→GND  SDA→GPIO6  SCL→GPIO7  LPn→3V3  INT→GPIO5
//   SD card: CS→GPIO1  SCK→GPIO18  MOSI→GPIO19  MISO→GPIO20
//   Reset button: GPIO3 → GND
//
// Board:    "ESP32C6 Dev Module"  (esp32 ≥ 3.x)
// Libraries:
//   SparkFun VL53L5CX Arduino Library
//   ESP-Google-Sheet-Client  (mobizt)
//   ESP32WiFiEnterprise      (racoonx65)
//
// Credentials: copy secrets_template.h → secrets.h, fill in your values.
// ============================================================================

#include <Wire.h>
#include <WiFi.h>
#include <esp_sleep.h>
#include "time.h"
#include <ESP_Google_Sheet_Client.h>
#include <SparkFun_VL53L5CX_Library.h>
#include <SPI.h>
#include <SD.h>

#include "config.h"
#include "secrets.h"

#ifndef USE_HOME_WIFI
#include <WiFiEnterprise.h>
#endif

#include "tracking.h"

// ── hardware objects ────────────────────────────────────────────────────────
SparkFun_VL53L5CX       sensor;
VL53L5CX_ResultsData    sensorData;
OccupancyTracker        tracker;

// ── sensor interrupt ────────────────────────────────────────────────────────
volatile bool sensorDataReady = false;
void IRAM_ATTR onSensorInt() { sensorDataReady = true; }

// ── wifi / sheets state ─────────────────────────────────────────────────────
unsigned long lastWifiCheck   = 0;
unsigned long lastUpload      = 0;
unsigned long lastSDLog       = 0;
int           reconnectFails  = 0;
bool          wifiWasUp       = false;

// ── SD card state ───────────────────────────────────────────────────────────
bool sdReady = false;

// ── forward declarations ────────────────────────────────────────────────────
void initSensor();
void initSD();
bool connectWifi();
void checkWifi();
void appendToSheet();
void logToSD();
void handleResetButton();
void printBaseline();
void checkSleepSchedule();
void enterDeepSleep(int sleepSeconds);
void tokenStatusCallback(TokenInfo info);

unsigned long lastSleepCheck = 0;

unsigned long getEpoch() {
    time_t now;
    struct tm t;
    if (!getLocalTime(&t)) return 0;
    time(&now);
    return now;
}

// ============================================================================
// setup
// ============================================================================
void setup() {
    Serial.begin(115200);
    delay(500);
    Serial.println("\n=== Occupancy Counter VL53L5CX + Sheets ===");

    // ── sensor bus + init ───────────────────────────────────────────────────
    pinMode(RESET_BUTTON_PIN, INPUT_PULLUP);
    Wire.begin(SDA_PIN, SCL_PIN);
    Wire.setClock(I2C_CLOCK_HZ);
    initSensor();

    // ── SD card ──────────────────────────────────────────────────────────────
#if SD_ENABLED
    initSD();
#endif

    // ── wifi ─────────────────────────────────────────────────────────────────
    connectWifi();

    // ── NTP ─────────────────────────────────────────────────────────────────
    configTzTime(TZ_INFO, NTP_SERVER);
    Serial.println("[TIME] NTP configured");

    // ── Google Sheets auth ──────────────────────────────────────────────────
    GSheet.setTokenCallback(tokenStatusCallback);
    GSheet.setPrerefreshSeconds(10 * 60);
    GSheet.begin(GCP_CLIENT_EMAIL, GCP_PROJECT_ID, GCP_PRIVATE_KEY);

    // ── tracker ─────────────────────────────────────────────────────────────
    tracker.init();

    // Try to restore baseline from NVS (saved before last deep sleep).
    // If valid, skip calibration — mounting hasn't changed overnight.
    if (tracker.loadBaseline()) {
        Serial.println("[CAL]  Baseline restored from flash — skipping calibration");
        printBaseline();
    } else {
        Serial.println("[CAL]  No saved baseline — will calibrate (keep doorway clear)");
    }

    Serial.printf("[RUN]  Active — ceiling %d mm, shift %.1f rows, max %d tracks\n",
                  tracker.detect_ceiling, (float)MIN_CENTROID_SHIFT, MAX_TRACKS);

#if SLEEP_ENABLED
    // If we booted outside the active window, sleep immediately.
    // Wait briefly for NTP to sync so we have a valid clock.
    delay(2000);
    setenv("TZ", TZ_INFO, 1);
    tzset();
    struct tm bootTime;
    if (getLocalTime(&bootTime)) {
        int bootMin = bootTime.tm_hour * 60 + bootTime.tm_min;
        int sleepMin = SLEEP_HOUR * 60 + SLEEP_MINUTE;
        int wakeMin  = WAKE_HOUR * 60 + WAKE_MINUTE;

        bool inActiveWindow;
        if (wakeMin < sleepMin)
            inActiveWindow = (bootMin >= wakeMin && bootMin < sleepMin);
        else
            inActiveWindow = (bootMin >= wakeMin || bootMin < sleepMin);

        if (!inActiveWindow) {
            Serial.printf("[SLEEP] Booted at %02d:%02d — outside active window %02d:%02d–%02d:%02d\n",
                          bootTime.tm_hour, bootTime.tm_min,
                          WAKE_HOUR, WAKE_MINUTE, SLEEP_HOUR, SLEEP_MINUTE);
            int secsUntilWake;
            int nowSec = bootTime.tm_hour * 3600 + bootTime.tm_min * 60 + bootTime.tm_sec;
            int wakeSec = WAKE_HOUR * 3600 + WAKE_MINUTE * 60;
            secsUntilWake = (wakeSec - nowSec + 86400) % 86400;
            if (secsUntilWake < 60) secsUntilWake += 86400;
            enterDeepSleep(secsUntilWake);
        }
    } else {
        Serial.println("[SLEEP] NTP not ready — running without schedule");
    }
#endif
}

// ============================================================================
// loop
// ============================================================================
void loop() {
    unsigned long now = millis();

    // ── sleep schedule ──────────────────────────────────────────────────────
#if SLEEP_ENABLED
    checkSleepSchedule();
#endif

    // ── keep wifi alive ─────────────────────────────────────────────────────
    checkWifi();

    // ── reset button ────────────────────────────────────────────────────────
    handleResetButton();

    // ── sensor frame ────────────────────────────────────────────────────────
    if (!sensorDataReady) { delay(5); return; }
    sensorDataReady = false;

    if (!sensor.getRangingData(&sensorData)) return;

    int16_t dist[64];
    uint8_t stat[64];
    for (int i = 0; i < 64; i++) {
        dist[i] = sensorData.distance_mm[i];
        stat[i] = sensorData.target_status[i];
    }

    tracker.processFrame(dist, stat);

    if (!tracker.calibrated) {
        if (tracker.addCalibrationFrame(dist, stat)) {
            Serial.println("[CAL]  Calibration complete");
            printBaseline();
            if (tracker.saveBaseline())
                Serial.println("[CAL]  Baseline saved to flash");
        }
        return;
    }

    // ── periodic logging (only when doorway is clear to avoid stalling tracking) ──
    if (!tracker.tracking_active && now - lastUpload >= SHEETS_UPLOAD_INTERVAL_MS) {
        lastUpload = now;
        if (GSheet.ready()) appendToSheet();
    }
#if SD_ENABLED
    if (!tracker.tracking_active && now - lastSDLog >= SD_LOG_INTERVAL_MS) {
        lastSDLog = now;
        logToSD();
    }
#endif
}

// ============================================================================
// sensor init
// ============================================================================
void initSensor() {
    Serial.println("[INIT] Connecting to VL53L5CX …");
    int retries = 5;
    while (retries--) {
        if (sensor.begin(SENSOR_I2C_ADDR, Wire)) { Serial.println("[INIT] Sensor found"); break; }
        Serial.println("[INIT] Retrying …");
        delay(2000);
    }
    if (retries < 0) {
        Serial.println("[INIT] ERROR — sensor not detected");
        while (true) delay(1000);
    }
    sensor.setResolution(64);
    sensor.setRangingFrequency(SENSOR_FREQ_HZ);
    sensor.startRanging();

    pinMode(INT_PIN, INPUT_PULLUP);
    attachInterrupt(digitalPinToInterrupt(INT_PIN), onSensorInt, FALLING);

    Serial.printf("[INIT] 8x8 @ %d Hz, INT on GPIO%d\n", SENSOR_FREQ_HZ, INT_PIN);
}

// ============================================================================
// SD card
// ============================================================================
void initSD() {
    SPI.begin(SD_CLK_PIN, SD_MISO_PIN, SD_MOSI_PIN, SD_CS_PIN);
    if (!SD.begin(SD_CS_PIN)) {
        Serial.println("[SD]   Card mount failed — continuing without SD");
        sdReady = false;
        return;
    }
    sdReady = true;
    Serial.printf("[SD]   Card mounted — %lluMB\n",
                  SD.cardSize() / (1024 * 1024));
}

void logToSD() {
    if (!sdReady) return;

    setenv("TZ", TZ_INFO, 1);
    tzset();
    struct tm t;
    if (!getLocalTime(&t)) return;

    char filename[20];
    snprintf(filename, sizeof(filename), "/%04d-%02d-%02d.csv",
             t.tm_year + 1900, t.tm_mon + 1, t.tm_mday);

    bool newFile = !SD.exists(filename);
    File f = SD.open(filename, FILE_APPEND);
    if (!f) {
        Serial.println("[SD]   Write failed");
        return;
    }

    if (newFile)
        f.println("EpochTimestamp,Occupancy,Entry,Exit,Time");

    unsigned long epoch = getEpoch();
    char timeStr[20];
    strftime(timeStr, sizeof(timeStr), "%m/%d/%Y %H:%M:%S", &t);

    f.printf("%lu,%d,%d,%d,%s\n",
             epoch, tracker.occupancy, tracker.total_entries,
             tracker.total_exits, timeStr);
    f.close();
    Serial.println("[SD]   Row logged");
}

// ============================================================================
// WiFi — home (WPA2-PSK) or eduroam (WPA2-Enterprise)
// ============================================================================
bool connectWifi() {
#ifdef USE_HOME_WIFI
    Serial.printf("[WIFI] Connecting to %s …\n", HOME_SSID);
    WiFi.mode(WIFI_STA);
    WiFi.begin(HOME_SSID, HOME_PASSWORD);
    int tries = 40;
    while (WiFi.status() != WL_CONNECTED && tries-- > 0) { delay(500); Serial.print('.'); }
    Serial.println();
    bool ok = (WiFi.status() == WL_CONNECTED);
#else
    Serial.printf("[WIFI] Connecting to %s as %s …\n", EDUROAM_SSID, EDUROAM_USERNAME);
    bool ok = WiFiEnterprise.begin(EDUROAM_SSID, EDUROAM_USERNAME, EDUROAM_PASSWORD, true);
#endif
    if (ok) {
        Serial.printf("[WIFI] Connected — IP %s  RSSI %d dBm\n",
                      WiFi.localIP().toString().c_str(), WiFi.RSSI());
        wifiWasUp = true;
        reconnectFails = 0;
    } else {
        Serial.println("[WIFI] Connection failed");
    }
    return ok;
}

void checkWifi() {
    unsigned long now = millis();
    if (now - lastWifiCheck < WIFI_CHECK_INTERVAL_MS) return;
    lastWifiCheck = now;

    bool connected;
#ifdef USE_HOME_WIFI
    connected = (WiFi.status() == WL_CONNECTED);
#else
    connected = WiFiEnterprise.isConnected();
#endif

    if (connected) {
        if (!wifiWasUp) {
            Serial.printf("[WIFI] Reconnected — IP %s\n",
                          WiFi.localIP().toString().c_str());
            reconnectFails = 0;
        }
        wifiWasUp = true;
        return;
    }

    wifiWasUp = false;
    if (reconnectFails >= MAX_RECONNECT_ATTEMPTS) return;

    Serial.printf("[WIFI] Reconnect attempt %d/%d …\n",
                  reconnectFails + 1, MAX_RECONNECT_ATTEMPTS);
    if (!connectWifi()) reconnectFails++;
}

// ============================================================================
// Google Sheets append:
//   Column A = EpochTimestamp
//   Column B = Count (occupancy)
//   Column C = Entry (total_entries)
//   Column D = Exit  (total_exits)
//   Column E = Time (EST)  — human-readable
// ============================================================================
void appendToSheet() {
    unsigned long epoch = getEpoch();
    if (epoch == 0) {
        Serial.println("[SHEET] Skipped — no valid time yet");
        return;
    }

    setenv("TZ", TZ_INFO, 1);
    tzset();
    struct tm t;
    char timeStr[20];
    if (getLocalTime(&t))
        strftime(timeStr, sizeof(timeStr), "%m/%d/%Y %H:%M:%S", &t);
    else
        snprintf(timeStr, sizeof(timeStr), "unknown");

    FirebaseJson valueRange;
    valueRange.add("majorDimension", "COLUMNS");
    valueRange.set("values/[0]/[0]", epoch);                   // A
    valueRange.set("values/[1]/[0]", tracker.occupancy);       // B
    valueRange.set("values/[2]/[0]", tracker.total_entries);   // C
    valueRange.set("values/[3]/[0]", tracker.total_exits);     // D
    valueRange.set("values/[4]/[0]", timeStr);                 // E

    FirebaseJson response;
    bool ok = GSheet.values.append(&response,
                                   SPREADSHEET_ID,
                                   "Data!A2",
                                   &valueRange);
    if (ok) {
        Serial.printf("[SHEET] OK — occ:%d  in:%d  out:%d  heap:%lu\n",
                      tracker.occupancy, tracker.total_entries,
                      tracker.total_exits, (unsigned long)ESP.getFreeHeap());
    } else {
        Serial.printf("[SHEET] FAIL — %s\n", GSheet.errorReason().c_str());
    }
}

// ============================================================================
// sleep schedule
// ============================================================================
void checkSleepSchedule() {
    unsigned long now = millis();
    if (now - lastSleepCheck < SLEEP_CHECK_INTERVAL_MS) return;
    lastSleepCheck = now;

    setenv("TZ", TZ_INFO, 1);
    tzset();
    struct tm t;
    if (!getLocalTime(&t)) return;

    int nowMin   = t.tm_hour * 60 + t.tm_min;
    int sleepMin = SLEEP_HOUR * 60 + SLEEP_MINUTE;

    if (nowMin == sleepMin || (nowMin > sleepMin && nowMin <= sleepMin + 1)) {
        Serial.printf("[SLEEP] %02d:%02d — time to sleep\n", t.tm_hour, t.tm_min);
        Serial.printf("[SLEEP] Final: occ=%d  in=%d  out=%d\n",
                      tracker.occupancy, tracker.total_entries, tracker.total_exits);

        tracker.resetCount();
        appendToSheet();

        if (tracker.calibrated && tracker.saveBaseline())
            Serial.println("[SLEEP] Baseline saved to flash");

        sensor.stopRanging();

#if SD_ENABLED
        if (sdReady) { SD.end(); Serial.println("[SD]   Unmounted"); }
#endif

        int nowSec  = t.tm_hour * 3600 + t.tm_min * 60 + t.tm_sec;
        int wakeSec = WAKE_HOUR * 3600 + WAKE_MINUTE * 60;
        int sleepSecs = (wakeSec - nowSec + 86400) % 86400;
        if (sleepSecs < 60) sleepSecs += 86400;

        enterDeepSleep(sleepSecs);
    }
}

void enterDeepSleep(int sleepSeconds) {
    // ESP32-C3 can be unreliable with very long deep sleep timers.
    // Cap each sleep to 1 hour; setup() re-checks the clock on wake
    // and sleeps again if still outside the active window.
    const int MAX_SLEEP_SEC = 3600;
    int actual = (sleepSeconds > MAX_SLEEP_SEC) ? MAX_SLEEP_SEC : sleepSeconds;

    Serial.printf("[SLEEP] Deep sleep for %dm (total remaining %dh %dm)\n",
                  actual / 60, sleepSeconds / 3600, (sleepSeconds % 3600) / 60);
    Serial.flush();

    WiFi.disconnect(true);
    WiFi.mode(WIFI_OFF);

    esp_sleep_enable_timer_wakeup((uint64_t)actual * 1000000ULL);
    esp_deep_sleep_start();
}

// ============================================================================
// misc
// ============================================================================
unsigned long resetBtnDown   = 0;
bool          resetBtnActive = false;

void handleResetButton() {
    bool pressed = (digitalRead(RESET_BUTTON_PIN) == LOW);
    if (pressed && !resetBtnActive) { resetBtnDown = millis(); resetBtnActive = true; }
    if (!pressed) { resetBtnActive = false; return; }
    if (resetBtnActive && (millis() - resetBtnDown >= RESET_HOLD_MS)) {
        tracker.resetCount();
        tracker.clearSavedBaseline();
        tracker.resetCalibration();
        resetBtnActive = false;
        Serial.println("[BTN]  Reset — clear the doorway!");
        for (int i = 10; i > 0; i--) {
            Serial.printf("[BTN]  Calibrating in %d …\n", i);
            delay(1000);
        }
        Serial.println("[BTN]  Calibrating now");
    }
}

void printBaseline() {
    Serial.println("[CAL]  Baseline (mm):");
    for (int r = 0; r < 8; r++) {
        Serial.print("  ");
        for (int c = 0; c < 8; c++) Serial.printf("%5d", tracker.baseline[r * 8 + c]);
        Serial.println();
    }
}

void tokenStatusCallback(TokenInfo info) {
    if (info.status == token_status_error)
        GSheet.printf("[AUTH] ERROR — %s\n", GSheet.getTokenError(info).c_str());
    else
        GSheet.printf("[AUTH] %s — %s\n",
                      GSheet.getTokenType(info).c_str(),
                      GSheet.getTokenStatus(info).c_str());
}

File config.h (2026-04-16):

#ifndef CONFIG_H
#define CONFIG_H

// ============================================================================
// Pin Definitions (ESP32 + Pololu VL53L5CX carrier)
// ============================================================================
#define SDA_PIN             6
#define SCL_PIN             7
#define INT_PIN             5
#define RESET_BUTTON_PIN    3

// ============================================================================
// SD Card (SPI) — micro SD breakout module
//   Change these if your wiring differs.
// ============================================================================
#define SD_CS_PIN           1
#define SD_CLK_PIN          18
#define SD_MOSI_PIN         19
#define SD_MISO_PIN         20
#define SD_ENABLED          1     // set to 0 to disable SD logging entirely

// ============================================================================
// Google Sheets logging
// ============================================================================
#define SHEETS_UPLOAD_INTERVAL_MS  30000   // append a row every 30 s
#define SD_LOG_INTERVAL_MS         300000  // SD backup every 5 min
#define WIFI_CHECK_INTERVAL_MS     5000    // check eduroam link every 5 s
#define MAX_RECONNECT_ATTEMPTS     5       // then stop retrying until next reboot

// ============================================================================
// NTP / timezone
// ============================================================================
#define NTP_SERVER    "pool.ntp.org"
#define TZ_INFO       "EST5EDT,M3.2.0/02:00:00,M11.1.0/02:00:00"

// ============================================================================
// Sensor
// ============================================================================
#define SENSOR_I2C_ADDR       0x29
#define SENSOR_FREQ_HZ        15
#define I2C_CLOCK_HZ          400000

// ============================================================================
// Detection
// ============================================================================
#define DETECT_FLOOR_MM       100       // ignore closer than this (doors, fixtures, unreliable close zone)
#define DETECT_CEILING_MM     1000

// ============================================================================
// Blob detection & multi-target tracking
//
// Each frame: find connected blobs of occupied cells via BFS.
// Associate blobs to persistent tracks by nearest centroid.
// When a track disappears, evaluate its enter→exit row shift to
// determine crossing direction.  Each person gets their own track,
// so back-to-back crossings count correctly.
// ============================================================================
#define MAX_BLOBS             4
#define MAX_TRACKS            4
#define MIN_BLOB_SIZE         2     // min cells to form a valid blob
#define MAX_ASSOC_DIST        3.0f  // max centroid distance (grid cells) for track↔blob match
#define MIN_CROSSING_FRAMES   3     // min frames for a real crossing (~200 ms at 15 Hz)
#define MAX_CROSSING_FRAMES   90    // timeout: person lingering (~6 s at 15 Hz)
#define MIN_CENTROID_SHIFT    1.5f  // min row shift (grid rows) to count as a crossing
#define MISS_GRACE_FRAMES     5     // frames to tolerate track dropout (~333 ms at 15 Hz)
#define ENTRY_DIR             -1    // 1 = row-increasing = entry, -1 = row-decreasing = entry

// ============================================================================
// Min-distance filter (UM2600 §6.2)
// ============================================================================
#define MIN_FILTER_DEPTH      3

// ============================================================================
// Static-object rejection
// ============================================================================
#define STATIC_MARGIN_MM      100

// ============================================================================
// Calibration (runs automatically during first ~2 s — keep doorway empty!)
// ============================================================================
#define CALIB_FRAMES          30
#define CALIB_MAX_DIST_MM     4000

// ============================================================================
// Sleep schedule — device deep-sleeps outside these hours.
// On wake it reboots fresh (counts reset, baseline restored from flash).
// Set SLEEP_ENABLED to 0 to run 24/7.
// ============================================================================
#define SLEEP_ENABLED         1
#define SLEEP_HOUR            21    // go to sleep at this hour (24h format)
#define SLEEP_MINUTE          30    // ... and this minute  → 21:30 = 9:30 PM
#define WAKE_HOUR             6    // wake up at this hour
#define WAKE_MINUTE           30    // ... and this minute  → 06:30 = 6:30 AM
#define SLEEP_CHECK_INTERVAL_MS 30000  // check clock every 30 s
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

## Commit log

2026-04-09 Occupancy counter with multi-blob tracking, Sheets logging, SD backup, and Grafana dashboard
    VL53L5CX 8x8 ToF sensor on ESP32-C3 with BFS blob detection, greedy
    multi-target association, merge-hold for shoulder-brush rejection,
    NVS baseline persistence across deep sleep cycles, WPA2-Enterprise
    (eduroam) by default, optional WPA2-PSK, Google Sheets cloud logging,
    SD card CSV backup, and configurable sleep schedule.
2026-04-09 Remove merge-hold logic, add 10s reset countdown
    Merge-hold was freezing track association when blobs overlapped,
    causing missed back-to-back crossings in single-width doorways.
    Tracking now runs greedy association every frame without any freeze
    window. Reset button now gives a 10-second countdown so you can
    clear the doorway before recalibration begins.
    [OccupancyCounter.ino, config.h, tracking.h]
2026-04-16 ESP32-C6 migration, idle-only uploads, staggered SD logging
    Updated pin assignments for ESP32-C6 (SDA=6, SCL=7, INT=5, BTN=3,
    SD CS=1/SCK=18/MOSI=19/MISO=20). Sheets uploads and SD writes now
    only fire when tracking_active is false to prevent blocking the
    15 Hz tracking pipeline. SD logging runs on its own 5-minute timer
    independent of the 30-second Sheets interval. Re-enabled sleep
    schedule. README and sketch header updated to reflect all changes.
    [OccupancyCounter.ino, config.h]
2026-04-20 Fix UM2600 citation link
    The References section mislabeled AN5765 as UM2600. Split into two
    separate entries: AN5765 for the VL53L5CX ranging guide, and UM2600
    for the people-counting app note where the min-distance filter
    technique (§6.2) originates. UM2600 is originally for the VL53L1X;
    we adapt the rolling-minimum filter to the L5CX 8x8 grid.
2026-04-23 Add live web UI and Grafana dashboard GIFs to README
    Embeds two demo animations: the live web UI showing the 8x8 sensor
    grid with real-time occupancy counts, and the Grafana dashboard
    showing occupancy stat tiles and time-series chart. Placed near the
    top of the README and in the existing Grafana Dashboard section.
2026-04-27 Add standalone tracking debug display under tools/
    Bundles the previously-separate TrackingDebugDisplay sketch into a
    tools/debug-display/ subfolder so sponsors and future teams have
    everything in one place. The debug sketch hosts a self-contained
    WiFi access point and serves a live web visualization of the
    tracking pipeline (8x8 grid, blobs, tracks, crossing decisions),
    useful for sensor placement and calibration validation without
    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
2026-05-04 Added CAD files
    [Button_Holder.f3d, Button_Holder.stl, Final_Enclosure.f3d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]
